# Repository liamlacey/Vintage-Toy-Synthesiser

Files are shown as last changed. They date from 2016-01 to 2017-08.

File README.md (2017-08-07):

# Vintage Toy Synthesiser #

Vintage Toy Synthesiser was the winning project of the [Element14 Music Tech Design Challenge](https://www.element14.com/community/community/design-challenges/musictech) where I converted a wooden vintage toy piano into a standalone digital synthesiser. See the [project blog](https://www.element14.com/community/community/design-challenges/musictech/blog/tags#/?tags=project_vintage) to see the full development process of the project. 

alt vintage-toy-synthesiser

## Project Proposal ##

The original project proposal specification was as follows:
+ Develop a digital synthesis engine that can generate and modify synthesised sounds
+ Modify the existing key mechanism so that it can trigger sounds and control velocity modulation on the synthesis engine
+ Add a set of potentiometers, switches and other controls to the existing piano enclosure for controlling the synthesis engine
+ Add an audio output for connecting the instrument to external speakers and recording equipment
+ Add MIDI I/O so that the instrument can be integrated into existing music production systems
+ Keep the existing aesthetic character of the vintage toy piano

For more info see the full [project proposal](https://www.element14.com/community/community/design-challenges/musictech/blog/2015/12/20/my-music-tech-design-challenge-project-proposal--vintage-toy-synthesiser).

## Hardware/Software Architecture ##

The synthesiser uses a couple of different hardware software platforms:
+ The brain and sound engine of the synthesiser are seperate Linux applications running on a [BeagleBone Black](https://beagleboard.org/black) board, which communicate via software sockets. The brain application is developed in C, and the sound engine application is developed in C++ using the [Maximilian](https://github.com/micknoise/Maximilian) Audio DSP library and [RtAudio](https://www.music.mcgill.ca/~gary/rtaudio/). See the [BeagleBone Black directory](https://github.com/liamlacey/Vintage-Toy-Synthesiser/tree/master/Code/BBB/) for the code for these applications.
+ The keyboard and panel use [Arduino Pro Mini](https://www.arduino.cc/en/Main/ArduinoBoardProMini) boards for sensor/control scanning. The Arduinos communicate with the BeagleBone Black via serial. See the [Arduino directory](https://github.com/liamlacey/Vintage-Toy-Synthesiser/tree/master/Code/Arduino) for the keyboard and panel code.
+ There is a Mac OS X editor application for saving and loading patches on the synth, written in C++ using the [JUCE](https://www.juce.com) framework. See the [VtsEditor directory](https://github.com/liamlacey/Vintage-Toy-Synthesiser/tree/master/Code/VtsEditor) for the code.

For more info on the software architecture see [here](https://www.element14.com/community/community/design-challenges/musictech/blog/2016/02/12/vintage-toy-synthesiser-software-architecture).

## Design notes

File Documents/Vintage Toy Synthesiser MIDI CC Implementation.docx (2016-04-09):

Vintage Toy Synthesiser MIDI CC Implementation

All the parameters of the Vintage Toy Synthesiser can be controlled externally via MIDI CC messages. Also the dials and switches of the front panel can transmit MIDI CCs. Below is a list of all the CCs that are used.

Parameter Category | Parameter | CC Number | CC Range/Values | Notes
Filter | Cutoff | 74 | 0 – 127
| Resonance | 19 | 0 – 127
| LP Mix | 26 | 0 – 127
| HP Mix | 28 | 0 – 127
| BP Mix | 27 | 0 – 127
| Notch Mix | 29 | 0 – 127
Oscillators | Sine Mix | 14 | 0 – 127
| Triangle Mix | 15 | 0 – 127
| Sawtooth Mix | 16 | 0 – 127
| Square Mix | 18 | 0 – 127
| Pulse Mix | 17 | 0 – 127
| Pulse Amount | 3 | 0 – 127
| Sine Note | 33 | 40 – 88 | Bipolar, 64 is midpoint
| Triangle Note | 34 | 40 – 88 | Bipolar, 64 is midpoint
| Sawtooth Note | 35 | 40 – 88 | Bipolar, 64 is midpoint
| Square Note | 37 | 40 – 88 | Bipolar, 64 is midpoint
| Pulse Note | 36 | 40 – 88 | Bipolar, 64 is midpoint
| Phase Spread | 20 | 0 – 127
Amplitude Envelope | Amount | 7 | 0 – 127
| Attack | 73 | 0 – 127
| Decay | 75 | 0 – 127
| Sustain | 79 | 0 – 127
| Release | 72 | 0 – 127
Filter Envelope | Attack | 22 | 0 – 127
| Decay | 23 | 0 – 127
| Sustain | 24 | 0 – 127
| Release | 25 | 0 – 127
LFO | Shape | 50 | 0 – 3 | 0 = sine, 1 = tri, 2 = saw, 3 = square
| Rate | 47 | 0 – 127
| Depth | 48 | 1 – 127 | Bipolar, 64 is midpoint
Modulation Depths | LFO to Amplitude | 58 | 1 – 127 | Bipolar, 64 is midpoint
| LFO to Cutoff | 112 | 1 – 127 | Bipolar, 64 is midpoint
| LFO to Resonance | 56 | 1 – 127 | Bipolar, 64 is midpoint
| Velocity to Amplitude | 63 | 1 – 127 | Bipolar, 64 is midpoint
| Velocity to Cutoff | 109 | 1 – 127 | Bipolar, 64 is midpoint
| Velocity to Resonance | 110 | 1 – 127 | Bipolar, 64 is midpoint
Keyboard/ Voices | Scale | 102 | 0 – 7 | 0 = chromatic, 1 = major, 2 = major pentatonic, 3 = minor, 4 = minor pentatonic, 5 = melodic minor, 6 = harmonic minor, 7 = blues
| Octave | 114 | 61 - 67 | Bipolar, 64 is midpoint
| Transpose | 106 | 58 - 70 | Bipolar, 64 is midpoint
| Voice Mode | 103 | 0 or 127 | 0 = mono, 127 = poly
Global | Distortion Amount | 13 | 0 – 127
| Vintage Amount | 107 | 0 – 127

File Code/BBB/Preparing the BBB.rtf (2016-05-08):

Preparing a BeagleBone Black for the Vintage Toy Synthesiser Project

Note that for steps 1 and 2 I have included a replacement file that can be used instead of doing these steps, however I’m not 100% certain if this file will work on all BBBs which may have slightly different OS’s on them.

1. Enable all UART ports by adding the following line to /boot/uboot/uEnv.txt or /boot/uEnv.txt: optargs=capemgr.enable_partno=BB-UART1,BB-UART2,BB-UART4,BB-UART5. This info was from the following guide - http://tinkernow.com/2015/01/beaglebone-black-rs232-uart-setup/. A reboot is needed for this change to take effect.
2. Set USB audio to be the default audio device:
⁃ Disable HDMI audio by adding or uncommenting the following line from /boot/uboot/uEnv.txt or /boot/uEnv.txt: optargs=capemgr.disable_partno=BB-BONELT-HDMI,BB-BONELT-HDMIN
⁃ Edit the following line of /etc/modprobe.d/alsa-base.conf: options snd-usb-audio index=-2, changing it to: options snd-usb-audio index=0.
⁃ This info was from the following guide - http://andicelabs.com/2014/03/usb-audio-beaglebone/. A reboot is needed for this to take effect.
3. Create the following directories:
⁃ /usr/VintageToySynthProject/
⁃ /usr/VintageToySynthProject/VintageBrain/
⁃ /usr/VintageToySynthProject/VintageSoundEngine/
⁃ /var/vintageToySynthProject/
4. Create a systemd service so that the startup script can be run on boot. See the VintageToySynthProject/vintageToySynthStartup.sh file for more info.

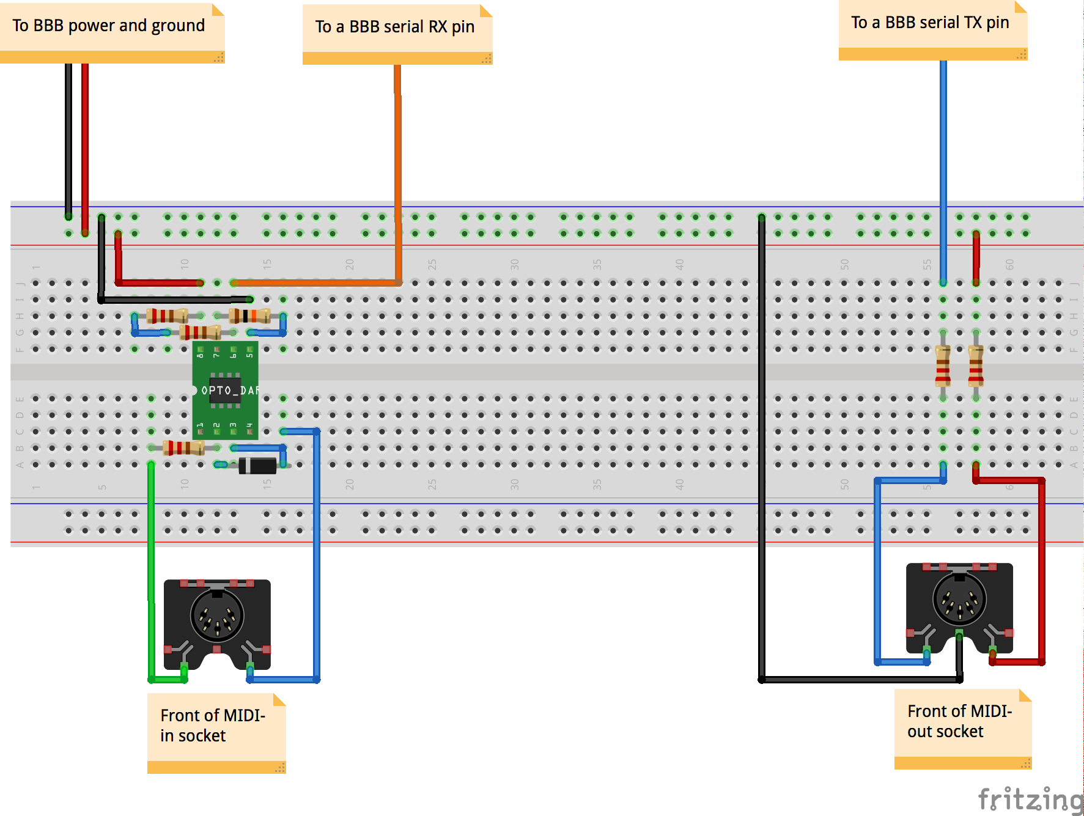
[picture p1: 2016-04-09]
Schematics and Design Files/MIDI/MIDI IO circuit.png

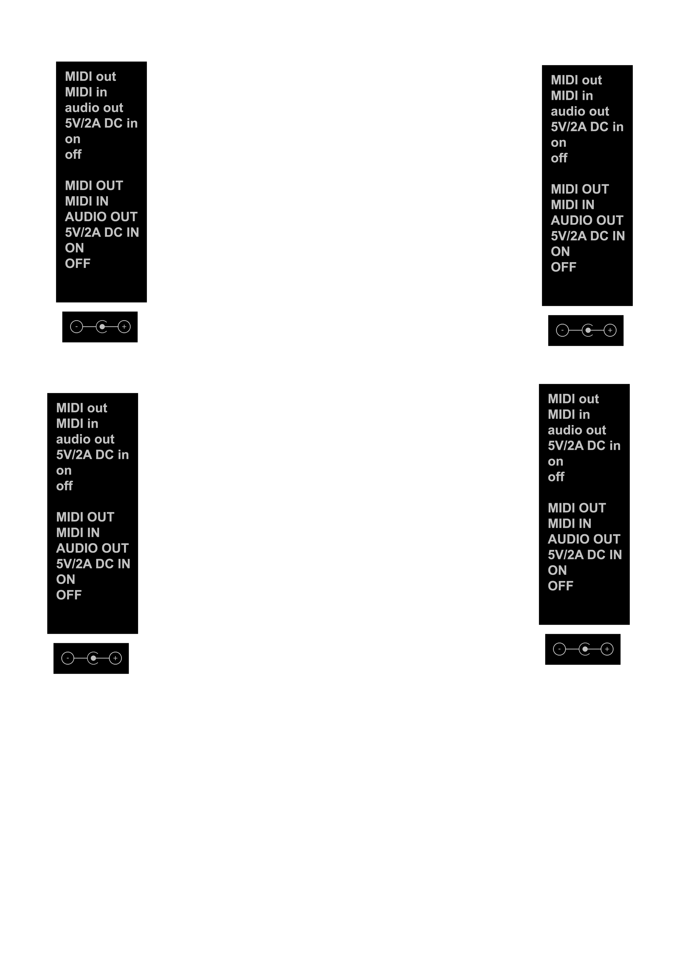
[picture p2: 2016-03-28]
Schematics and Design Files/Panel/Back panel labels.png

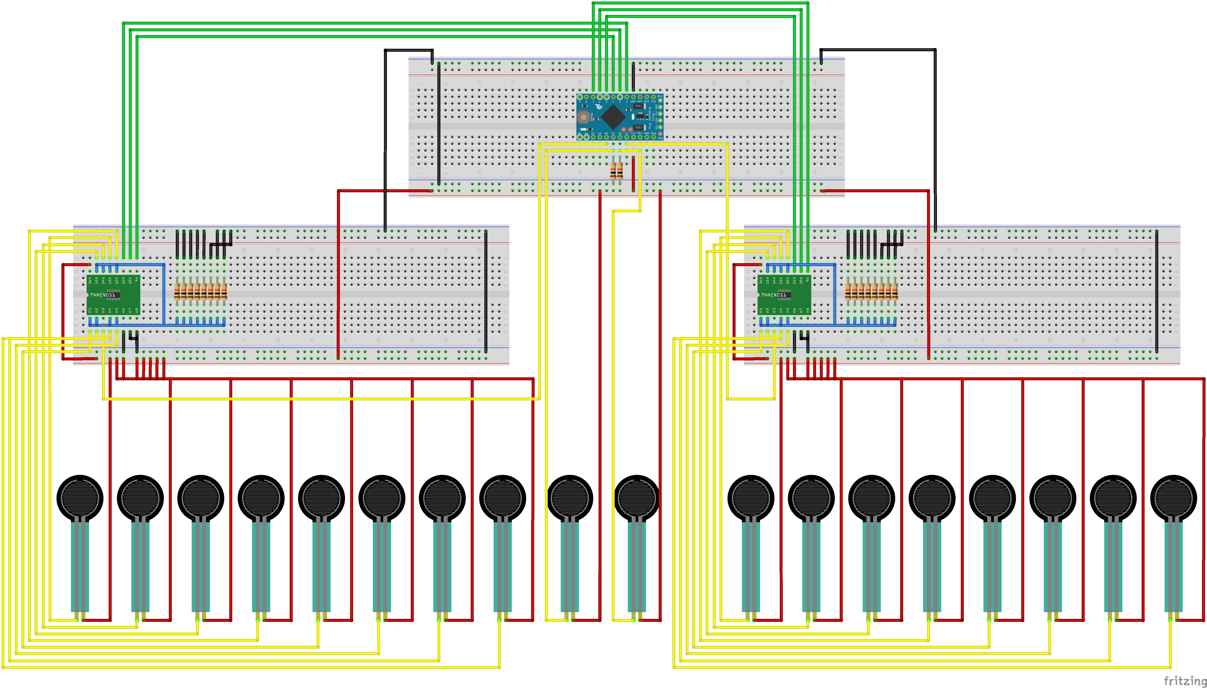
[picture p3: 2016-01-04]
Schematics and Design Files/Keyboard/key mech circuit v2_bb.png

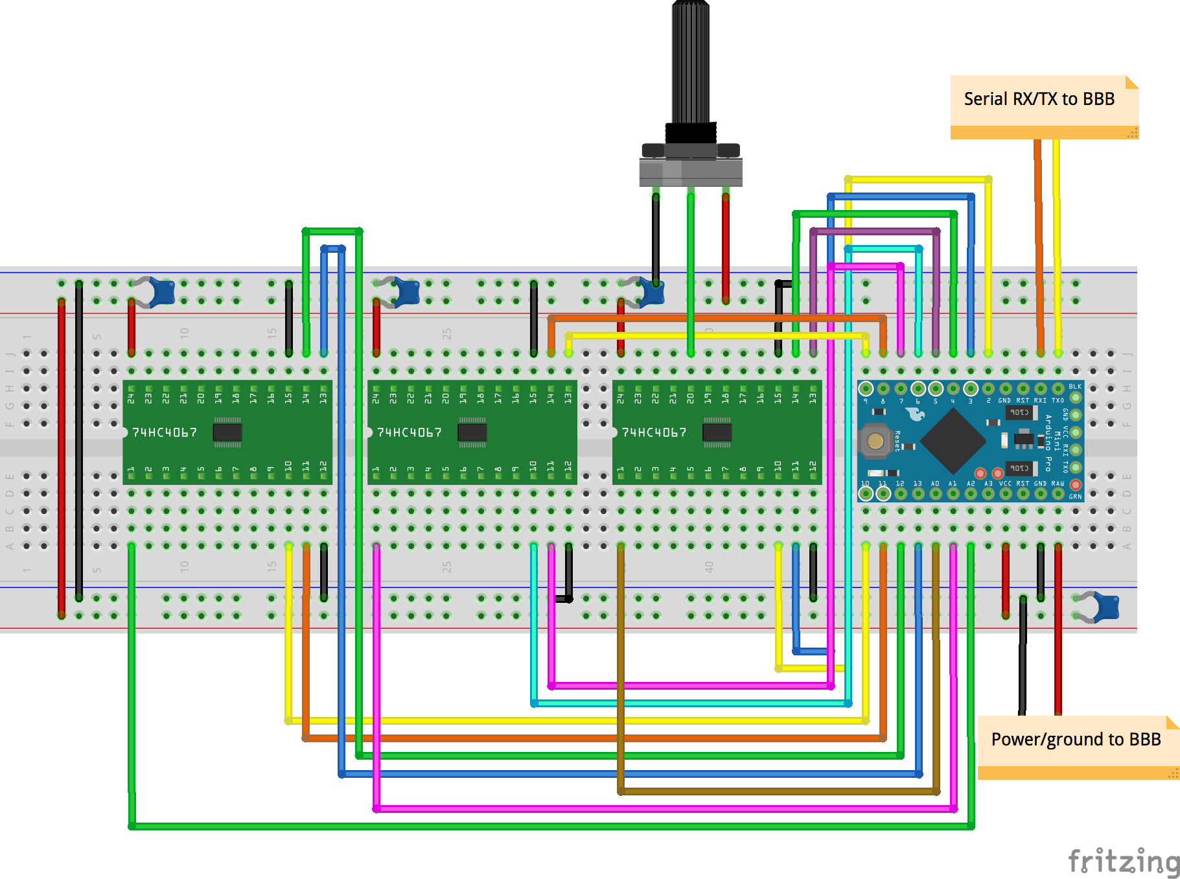
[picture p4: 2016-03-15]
Schematics and Design Files/Panel/panel circuit_bb.png

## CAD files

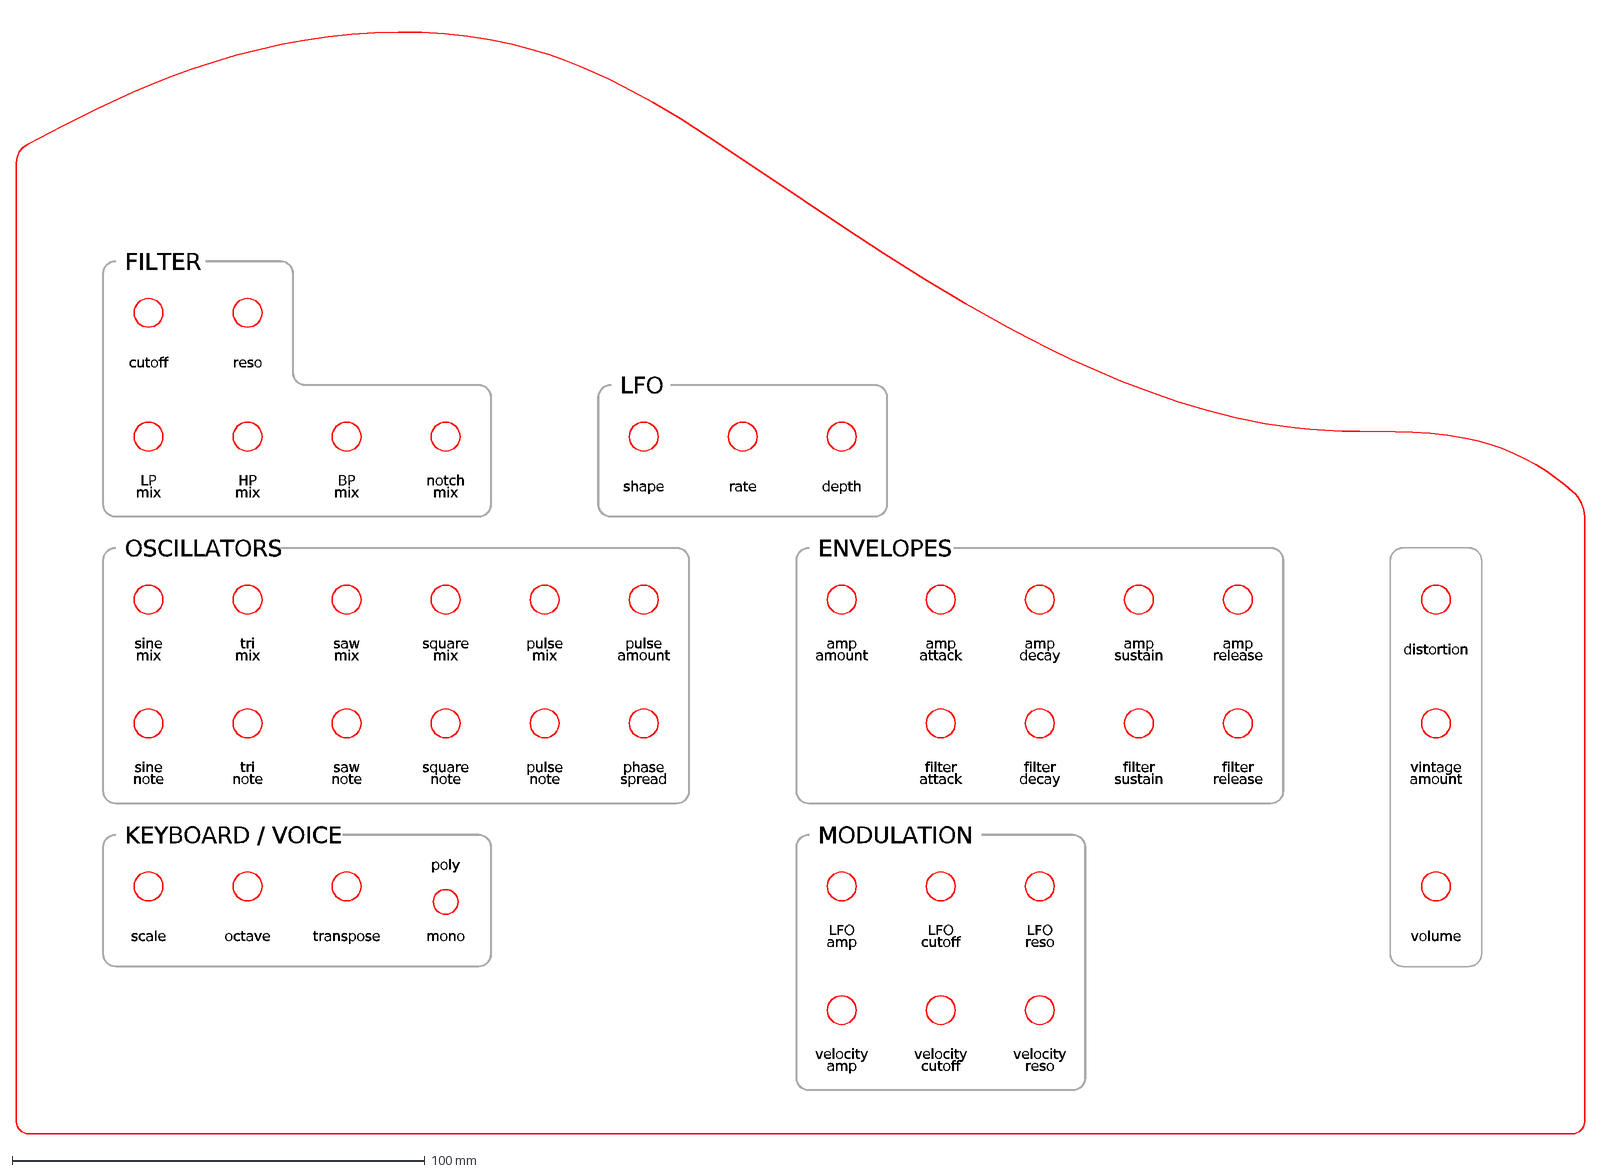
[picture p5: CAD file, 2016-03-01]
Schematics and Design Files/Panel/Synth_Panel_v2_3mm_Acrylic.dxf
cutoff
reso
transpose
scale
octave
mono
pulse amount
phase spread
pulse note
pulse mix
square mix
saw mix
tri mix
sine mix
sine note
tri note
saw note
square note
LP mix
HP mix
BP mix
notch mix
shape
rate
depth
LFO amp
LFO reso
velocity amp
velocity cutoff
velocity reso
distortion
vintage amount
volume
LFO cutoff
poly
FILTER
LFO
OSCILLATORS
amp amount
amp attack
amp decay
amp sustain
amp release
filter attack
filter decay
filter sustain
filter release
ENVELOPES
KEYBOARD / VOICE
MODULATION

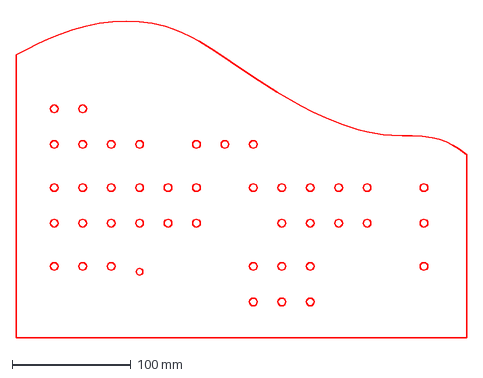
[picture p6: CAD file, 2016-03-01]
Schematics and Design Files/Panel/Synth_Panel_v1_3mm_plywood.dxf
380.0 x 270.9 mm

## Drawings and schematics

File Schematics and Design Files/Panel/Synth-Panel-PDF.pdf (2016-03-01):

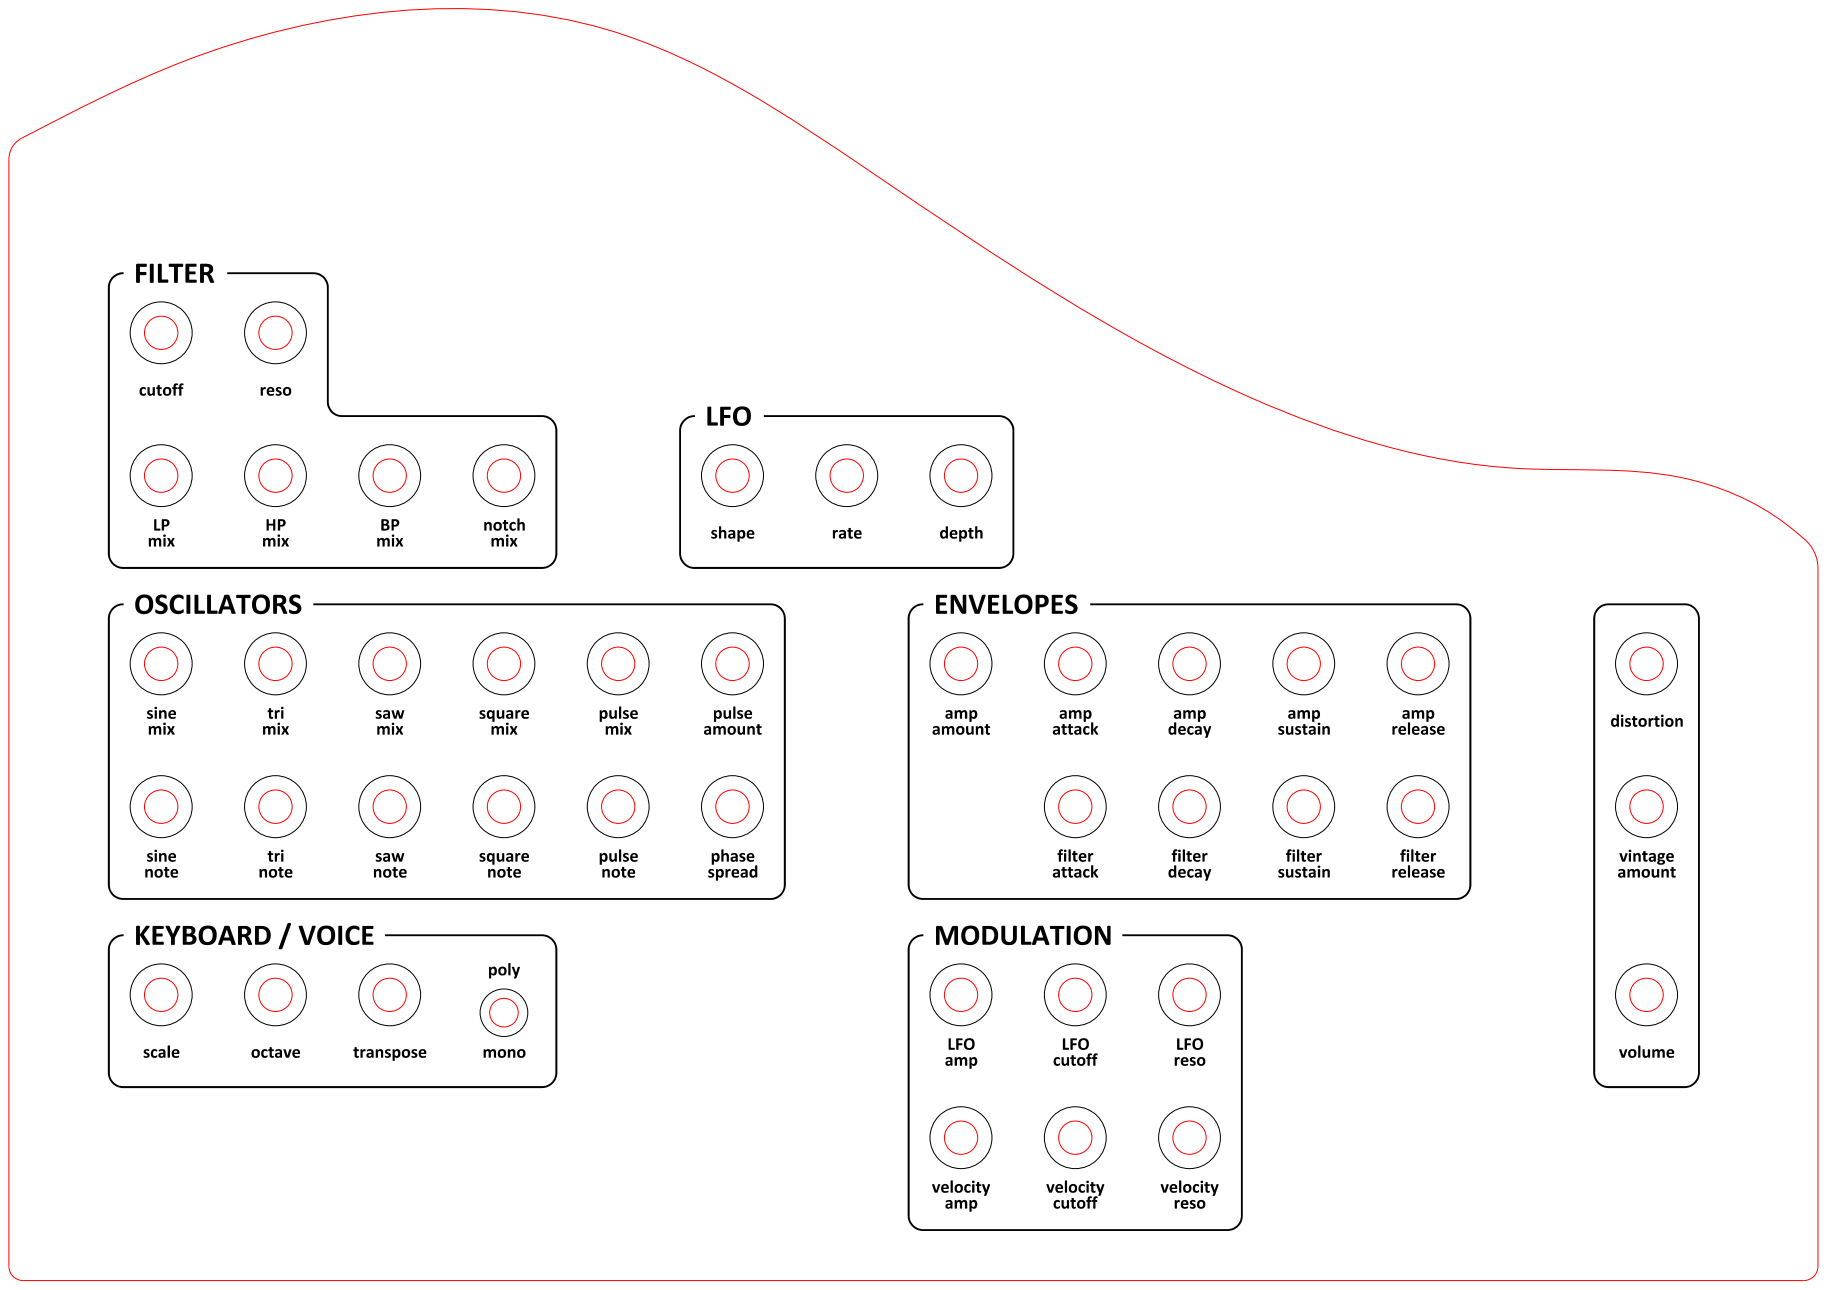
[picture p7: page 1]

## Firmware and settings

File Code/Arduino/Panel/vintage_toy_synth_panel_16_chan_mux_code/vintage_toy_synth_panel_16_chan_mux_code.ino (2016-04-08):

/*
   Vintage Toy Synthesiser Project - panel code.

   This the code for the Arduino Pro Mini attached to the piano's panel.
   This particular code is for using up to 4 16-channel multiplexers.

   All pins are used for the following:
   2 - 5: Mux1 select output pins
   6 - 9: Mux2 select output pins
   10 - 13: Mux3 select output pins
   A4 - A7 (as digital outputs): Mux4 select output pins
   A0: Mux1 input pin
   A1: Mux2 input pin
   A3: Mux3 input pin
   A4: Mux4 input pin

   Note that Mux4 may not be connected, but this code allows for it to be
   used. Mux4 mist be connected if NUM_OF_CONTROLS is greater than 16 * 3.

   //REMEMBER THAT ANY SERIAL DEBUGGING HERE MAY SCREW UP THE SERIAL COMMS TO THE BBB!
*/

//==========================================

//set to 1 when we want to debug to serial monitor rather than send data to the BBB
const byte DEBUG_MODE = 0;

//The number of pots/switches attached
const byte NUM_OF_CONTROLS = 43;

//for dev
const byte FIRST_CONTROL = 0;
const byte LAST_CONTROL = 42;

//The previous anologue value received from each control
int prevAnalogueValue[NUM_OF_CONTROLS] = {0};
//The previous param/MIDI value sent by each control
byte prevParamValue[NUM_OF_CONTROLS] = {0};

//MIDI channel we want to use
const byte midiChan = 0;

const byte VAL_CHANGE_OFFSET = 8;

//==========================================
//param data for each control

struct ControlParamData
{
  const byte cc_num;
  const byte cc_min_val;
  const byte cc_max_val;
  const bool is_depth_param;
};

ControlParamData controlParamData[NUM_OF_CONTROLS] =
{
  {.cc_num = 74, .cc_min_val = 0, .cc_max_val = 127, false}, //0 - PARAM_FILTER_CUTOFF
  {.cc_num = 19, .cc_min_val = 0, .cc_max_val = 127, false}, //1 - PARAM_FILTER_RESO
  {.cc_num = 26, .cc_min_val = 0, .cc_max_val = 127, false}, //2 - PARAM_FILTER_LP_MIX
  {.cc_num = 28, .cc_min_val = 0, .cc_max_val = 127, false}, //3 - PARAM_FILTER_HP_MIX
  {.cc_num = 27, .cc_min_val = 0, .cc_max_val = 127, false}, //4 - PARAM_FILTER_BP_MIX
  {.cc_num = 29, .cc_min_val = 0, .cc_max_val = 127, false}, //5 - PARAM_FILTER_NOTCH_MIX
  {.cc_num = 50, .cc_min_val = 0, .cc_max_val = 3, false}, //6 - PARAM_LFO_SHAPE
  {.cc_num = 47, .cc_min_val = 0, .cc_max_val = 127, false}, //7 - PARAM_LFO_RATE
  {.cc_num = 48, .cc_min_val = 1, .cc_max_val = 127, true}, //8 - PARAM_LFO_DEPTH
  {.cc_num = 14, .cc_min_val = 0, .cc_max_val = 127, false}, //9 - PARAM_OSC_SINE_LEVEL
  {.cc_num = 15, .cc_min_val = 0, .cc_max_val = 127, false}, //10 - PARAM_OSC_TRI_LEVEL
  {.cc_num = 16, .cc_min_val = 0, .cc_max_val = 127, false}, //11 - PARAM_OSC_SAW_LEVEL
  {.cc_num = 18, .cc_min_val = 0, .cc_max_val = 127, false}, //12 - PARAM_OSC_SQUARE_LEVEL
  {.cc_num = 17, .cc_min_val = 0, .cc_max_val = 127, false}, //13 - PARAM_OSC_PULSE_LEVEL
  {.cc_num = 3, .cc_min_val = 0, .cc_max_val = 127, false}, //14 - PARAM_OSC_PULSE_AMOUNT
  {.cc_num = 7, .cc_min_val = 0, .cc_max_val = 127, false}, //15 - PARAM_AEG_AMOUNT
  {.cc_num = 73, .cc_min_val = 0, .cc_max_val = 127, false}, //16 - PARAM_AEG_ATTACK
  {.cc_num = 75, .cc_min_val = 0, .cc_max_val = 127, false}, //17 - PARAM_AEG_DECAY
  {.cc_num = 79, .cc_min_val = 0, .cc_max_val = 127, false}, //18 - PARAM_AEG_SUSTAIN
  {.cc_num = 72, .cc_min_val = 0, .cc_max_val = 127, false}, //19 - PARAM_AEG_RELEASE
  {.cc_num = 13, .cc_min_val = 0, .cc_max_val = 127, false}, //20 - PARAM_FX_DISTORTION_AMOUNT
  {.cc_num = 33, .cc_min_val = 40, .cc_max_val = 88, false}, //21 - PARAM_OSC_SINE_NOTE
  {.cc_num = 34, .cc_min_val = 40, .cc_max_val = 88, false}, //22 - PARAM_OSC_TRI_NOTE
  {.cc_num = 35, .cc_min_val = 40, .cc_max_val = 88, false}, //23 - PARAM_OSC_SAW_NOTE
  {.cc_num = 37, .cc_min_val = 40, .cc_max_val = 88, false}, //24 - PARAM_OSC_SQUARE_NOTE
  {.cc_num = 36, .cc_min_val = 40, .cc_max_val = 88, false}, //25 - PARAM_OSC_PULSE_NOTE
  {.cc_num = 20, .cc_min_val = 0, .cc_max_val = 127, false}, //26 - PARAM_OSC_PHASE_SPREAD
  {.cc_num = 22, .cc_min_val = 0, .cc_max_val = 127, false}, //27 - PARAM_FEG_ATTACK
  {.cc_num = 23, .cc_min_val = 0, .cc_max_val = 127, false}, //28 - PARAM_FEG_DECAY
  {.cc_num = 24, .cc_min_val = 0, .cc_max_val = 127, false}, //29 - PARAM_FEG_SUSTAIN
  {.cc_num = 25, .cc_min_val = 0, .cc_max_val = 127, false}, //30 - PARAM_FEG_RELEASE
  {.cc_num = 107, .cc_min_val = 0, .cc_max_val = 127, false}, //31 - PARAM_GLOBAL_VINTAGE_AMOUNT
  {.cc_num = 102, .cc_min_val = 0, .cc_max_val = 7, false}, //32 - PARAM_KEYS_SCALE
  {.cc_num = 114, .cc_min_val = 61, .cc_max_val = 67, false}, //33 - PARAM_KEYS_OCTAVE
  {.cc_num = 106, .cc_min_val = 58, .cc_max_val = 70, false}, //34 - PARAM_KEYS_TRANSPOSE
  {.cc_num = 103, .cc_min_val = 127, .cc_max_val = 0, false}, //35 - PARAM_VOICE_MODE
  {.cc_num = 58, .cc_min_val = 1, .cc_max_val = 127, true}, //36 - PARAM_MOD_LFO_AMP
  {.cc_num = 112, .cc_min_val = 1, .cc_max_val = 127, true}, //37 - PARAM_MOD_LFO_CUTOFF
  {.cc_num = 56, .cc_min_val = 1, .cc_max_val = 127, true}, //38 - PARAM_MOD_LFO_RESO
  {.cc_num = 9, .cc_min_val = 0, .cc_max_val = 100, false}, //39 - PARAM_GLOBAL_VOLUME
  {.cc_num = 63, .cc_min_val = 1, .cc_max_val = 127, true}, //40 - PARAM_MOD_VEL_AMP
  {.cc_num = 109, .cc_min_val = 1, .cc_max_val = 127, true}, //41 - PARAM_MOD_VEL_CUTOFF
  {.cc_num = 110, .cc_min_val = 1, .cc_max_val = 127, true}, //42 - PARAM_MOD_VEL_RESO
};

//FOR DEVELOPMENT
//ControlParamData controlParamData[NUM_OF_CONTROLS] =
//{
//
//   {.cc_num = 0, .cc_min_val = 0, .cc_max_val = 127},
//   {.cc_num = 1, .cc_min_val = 0, .cc_max_val = 127},
//   {.cc_num = 2, .cc_min_val = 0, .cc_max_val = 127},
//   {.cc_num = 3, .cc_min_val = 0, .cc_max_val = 127},
//   {.cc_num = 4, .cc_min_val = 0, .cc_max_val = 127},
//   {.cc_num = 5, .cc_min_val = 0, .cc_max_val = 127},
//   {.cc_num = 6, .cc_min_val = 0, .cc_max_val = 127},
//   {.cc_num = 7, .cc_min_val = 0, .cc_max_val = 127},
//   {.cc_num = 8, .cc_min_val = 0, .cc_max_val = 127},
//   {.cc_num = 9, .cc_min_val = 0, .cc_max_val = 127},
//   {.cc_num = 10, .cc_min_val = 0, .cc_max_val = 127},
//   {.cc_num = 11, .cc_min_val = 0, .cc_max_val = 127},
//   {.cc_num = 12, .cc_min_val = 0, .cc_max_val = 127},
//   {.cc_num = 13, .cc_min_val = 0, .cc_max_val = 127},
//   {.cc_num = 14, .cc_min_val = 0, .cc_max_val = 127},
//   {.cc_num = 15, .cc_min_val = 0, .cc_max_val = 127},
//   {.cc_num = 16, .cc_min_val = 0, .cc_max_val = 127},
//   {.cc_num = 17, .cc_min_val = 0, .cc_max_val = 127},
//   {.cc_num = 18, .cc_min_val = 0, .cc_max_val = 127},
//   {.cc_num = 19, .cc_min_val = 0, .cc_max_val = 127},
//   {.cc_num = 20, .cc_min_val = 0, .cc_max_val = 127},
//   {.cc_num = 21, .cc_min_val = 0, .cc_max_val = 127},
//   {.cc_num = 22, .cc_min_val = 0, .cc_max_val = 127},
//   {.cc_num = 23, .cc_min_val = 0, .cc_max_val = 127},
//   {.cc_num = 24, .cc_min_val = 0, .cc_max_val = 127},
//   {.cc_num = 25, .cc_min_val = 0, .cc_max_val = 127},
//   {.cc_num = 26, .cc_min_val = 0, .cc_max_val = 127},
//   {.cc_num = 27, .cc_min_val = 0, .cc_max_val = 127},
//   {.cc_num = 28, .cc_min_val = 0, .cc_max_val = 127},
//   {.cc_num = 29, .cc_min_val = 0, .cc_max_val = 127},
//   {.cc_num = 30, .cc_min_val = 0, .cc_max_val = 127},
//   {.cc_num = 31, .cc_min_val = 0, .cc_max_val = 127},
//   {.cc_num = 32, .cc_min_val = 0, .cc_max_val = 127},
//   {.cc_num = 33, .cc_min_val = 0, .cc_max_val = 127},
//   {.cc_num = 34, .cc_min_val = 0, .cc_max_val = 127},
//   {.cc_num = 35, .cc_min_val = 0, .cc_max_val = 127},
//   {.cc_num = 36, .cc_min_val = 0, .cc_max_val = 127},
//   {.cc_num = 37, .cc_min_val = 0, .cc_max_val = 127},
//   {.cc_num = 38, .cc_min_val = 0, .cc_max_val = 127},
//   {.cc_num = 39, .cc_min_val = 0, .cc_max_val = 127},
//   {.cc_num = 40, .cc_min_val = 0, .cc_max_val = 127},
//   {.cc_num = 41, .cc_min_val = 0, .cc_max_val = 127},
//   {.cc_num = 42, .cc_min_val = 0, .cc_max_val = 127},
//};

void setup()
{
  //Setup serial comms for sending MIDI messages to BBB.
  //We don't need to use the MIDI baud rate (31250) here, as we're sending the messages to a general
  //serial output rather than a MIDI-specific output.
  Serial.begin(38400);

  //set all needed digital output pins
  for (byte i = 2; i <= 13; i++)
  {
    pinMode (i, OUTPUT);
  }

  pinMode (A4, OUTPUT);
  pinMode (A5, OUTPUT);
  pinMode (A6, OUTPUT);
  pinMode (A7, OUTPUT);

}

void loop()
{
  byte input_to_read;
  byte mux_input_pin;
  byte first_select_pin;

  //for each control
  for (byte control_num = FIRST_CONTROL; control_num <= LAST_CONTROL; control_num++)
  {
    //==========================================
    //==========================================
    //==========================================
    //Read analogue control input...

    //Select the mux/analogue pin we want to read from based on the control number
    //FIXME: there are probably equations I can use here instead.
    if (control_num < 16)
    {
      input_to_read = A0;
      mux_input_pin = control_num;
      first_select_pin = 2;
    }
    else if (control_num < 32)
    {
      input_to_read = A1;
      mux_input_pin = control_num - 16;
      first_select_pin = 6;
    }
    else if (control_num < 48)
    {
      input_to_read = A2;
      mux_input_pin = control_num - 32;
      first_select_pin = 10;
    }
    else
    {
      input_to_read = A3;
      mux_input_pin = control_num - 48;
      first_select_pin = A4;
    }

    //select the input pin on the mux we want to read from, by splitting
    //the mux input pin into bits and sending the bit values to mux select pins.
    int b0 = bitRead (mux_input_pin, 0);
    int b1 = bitRead (mux_input_pin, 1);
    int b2 = bitRead (mux_input_pin, 2);
    int b3 = bitRead (mux_input_pin, 3);
    digitalWrite (first_select_pin, b0);
    digitalWrite (first_select_pin + 1, b1);
    digitalWrite (first_select_pin + 2, b2);
    digitalWrite (first_select_pin + 3, b3);

    //read the input value
    int read_val = analogRead (input_to_read);

    //==========================================
    //==========================================
    //==========================================
    //Process analogue control input...

    //if the read control value is greater that +/-VAL_CHANGE_OFFSET from the last value
    //this is a quick dirty hack to prevent jitter
    if ((read_val > prevAnalogueValue[control_num] + VAL_CHANGE_OFFSET) ||
        (read_val < prevAnalogueValue[control_num] - VAL_CHANGE_OFFSET) ||
        (read_val == 0 && prevAnalogueValue[control_num] != 0) ||
        (read_val == 1023 && prevAnalogueValue[control_num] != 1023))
    {

      // Serial.print(control_num);
      // Serial.print(" ");
      // Serial.println(read_val);

      //store the value
      prevAnalogueValue[control_num] = read_val;

      //convert the control value into a param/MIDI CC value
      byte param_val = ConvertControlValToParamVal (control_num);

      //if this control is for a bipolar depth parameter
      if (controlParamData[control_num].is_depth_param == true)
      {
        //make sure the control definietly centres on the centre value of the parameter
        //by setting a certain window around the centre value to be set to the centre value

        if (param_val >= 63 && param_val <= 65)
        {
          param_val = 64;

        } //if (param_val >= 63 && param_val <= 65)

      } //if (controlParamData[control_num].is_bipolar_control == true)

      //if the param val is different from the last param val
      if (prevParamValue[control_num] != param_val)
      {
        //store the value
        prevParamValue[control_num] = param_val;

        //Send the param value as a MIDI CC message
        SendMidiMessage (0xB0 + midiChan, controlParamData[control_num].cc_num, prevParamValue[control_num]);

      } //if (prevParamValue[control_num] != param_val)

    } //if (prevAnalogueValue[control_num] != read_val)

    //slow down control reading to help prevent jitter.
    //it also means when pots are turned fast they only send a small number of values
    delay (2);

  } //for (byte control_num; control_num < NUM_OF_CONTROLS; control_num++)

  //==========================================
  //==========================================
  //==========================================
  //Read serial input...

  //if there is something to read on the serial port
  if (Serial.available())
  {
    //Serial.println ("Received messages from serial input");

    byte midi_in_buf[64];

    int num_of_bytes = Serial.readBytes (midi_in_buf, 64);

    //if received a request for all panel control values
    if (num_of_bytes == 3 && midi_in_buf[0] == 0xB0 && midi_in_buf[1] == 127 && midi_in_buf[2] == 1)
    {
      //send back all control values
      for (byte control_num = 0; control_num < NUM_OF_CONTROLS; control_num++)
      {
        SendMidiMessage (0xB0 + midiChan, controlParamData[control_num].cc_num, prevParamValue[control_num]);
      }

    } //if (num_of_bytes == 3 && midi_in_buf[0] == 0xB0 && midi_in_buf[1] = 127 && midi_in_buf[2] == 1)

  } //if (Serial.available())

}

//=====================================================
//=====================================================
//=====================================================
//Converts a control value into a param/MIDI CC value

byte ConvertControlValToParamVal (byte control_num)
{
  byte result;

  result = ((((float)controlParamData[control_num].cc_max_val - (float)controlParamData[control_num].cc_min_val) * (float)prevAnalogueValue[control_num]) / 1023.0) + (float)controlParamData[control_num].cc_min_val;

  return result;
}

//=====================================================
//=====================================================
//=====================================================
//Sends a 3 byte MIDI message to the serial output

void SendMidiMessage (byte cmd_byte, byte data_byte_1, byte data_byte_2)
{
  byte buf[3] = {cmd_byte, data_byte_1, data_byte_2};

  if (!DEBUG_MODE)
  {
    Serial.write (buf, 3);
  }

  else
  {
    Serial.print(buf[0]);
    Serial.print(" ");
    Serial.print(buf[1]);
    Serial.print(" ");
    Serial.println(buf[2]);
  }
}

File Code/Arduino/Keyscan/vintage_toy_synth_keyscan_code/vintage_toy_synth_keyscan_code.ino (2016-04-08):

//Toy Piano Synth Code, for front velostat switches only using multiplexers for the first and last 8 keys, with dedicated inputs for the middle two keys.
//TODO: improve this description
//*/

//TODO: document and DEFINE the inputs and outputs we are using for this code

//FIXME: some keys/sensors don't work as well as others - sensitivity is bad and can't reach high pressure values.
//If I can't fix these in the hardware, add fixes in the software (e.g. have upper limit pressure values for each key).

//REMEMBER THAT ANY SERIAL DEBUGGING HERE MAY SCREW UP THE SERIAL COMMS TO THE BBB!

//========================================================================================

//Number of keys on the piano
const int NUM_OF_KEYS = 18;

//MIDI channel we want to use
const int midiChan = 0;

//=======================================================================================

int INIT_PHASE_TIME = 10;

int PRESSURE_OFFSET = 100;

//Variables for storing certain values
int triggerVal[NUM_OF_KEYS] = {0};
bool noteIsOn[NUM_OF_KEYS] = {false};

unsigned long triggerTime[NUM_OF_KEYS] = {0};
int triggerInitVal[NUM_OF_KEYS] = {0};
bool inInitPhase[NUM_OF_KEYS] = {false};
byte prevPressureVal[NUM_OF_KEYS] = {0};

bool testLedState = false;

//array that holds the max analogue values they each sensor key can reach
const int maxSensorVals[NUM_OF_KEYS] =
{
  530, //0
  630, //1
  570, //2
  670, //3
  680, //4
  560, //5
  629, //6
  650, //7
  640, //8
  630, //9
  580, //10
  630, //11
  570, //12
  610, //13
  580, //14
  270, //15
  650, //16
  590 //17
};

void setup()
{
  //For sending MIDI messages to BBB.
  //We don't need to use the MIDI baud rate (31250) here, as we're sending the messages to a general
  //serial output rather than a MIDI-specific output.
  Serial.begin(38400);

  pinMode(2, OUTPUT);    // mux1 s0
  pinMode(3, OUTPUT);    // mux1 s1
  pinMode(4, OUTPUT);    // mux1 s2

  pinMode(5, OUTPUT);    // mux2 s0
  pinMode(6, OUTPUT);    // mux2 s1
  pinMode(7, OUTPUT);    // mux2 s2

  pinMode(13, OUTPUT);    // LED
}

void loop()
{
  //repeat the below code for each input/key
  for (int count; count < NUM_OF_KEYS; count++)
  {
    triggerVal[count] = 0;

    //==========================================
    //==========================================
    //==========================================
    //Read input
    //FIXME: this code could be tidier

    if (count < 8)
    {
      //select the bit/input
      int r0 = bitRead (count, 0);
      int r1 = bitRead (count, 1);
      int r2 = bitRead (count, 2);
      digitalWrite (2, r0);
      digitalWrite (3, r1);
      digitalWrite (4, r2);

      //read the input value
      triggerVal[count] = analogRead(A0);
    }

    else if (count == 8)
    {
      triggerVal[count] = analogRead(A1);
    }

    else if (count == 9)
    {
      triggerVal[count] = analogRead(A2);
    }

    else if (count > 9)
    {
      //select the bit/input

      int mux_input = count - 10;

      int r0 = bitRead (mux_input, 0);
      int r1 = bitRead (mux_input, 1);
      int r2 = bitRead (mux_input, 2);
      digitalWrite (5, r0);
      digitalWrite (6, r1);
      digitalWrite (7, r2);

      //read the input value
      triggerVal[count] = analogRead(A3);
    }

    //    if (triggerVal[count] > 0)
    //    {
    //      Serial.print(count);
    //      Serial.print(": ");
    //      Serial.println(triggerVal[count]);
    //    }

    //==========================================
    //==========================================
    //==========================================
    //Process input

    //==========================================
    //Initial press stuff (for working out velocity)

    //========================
    //if we've got the initial press of a key
    if (triggerVal[count] > 0 && inInitPhase[count] == false && noteIsOn[count] == false)
    {
      //stored the current time
      triggerTime[count] = millis();

      triggerInitVal[count] = 0;
      inInitPhase[count] = true;
    }

    //========================
    //if we're still holding down a key within the initial phase
    else if (triggerVal[count] > 0 && inInitPhase[count] == true && millis() < (triggerTime[count] + INIT_PHASE_TIME) && noteIsOn[count] == false)
    {
      //if the current val is higher than the current init val
      if (triggerVal[count] > triggerInitVal[count])
      {
        //store the current val
        triggerInitVal[count] = triggerVal[count];
      }
    }

    //========================
    //if a key is released before the initial phase is over
    else if (triggerVal[count] == 0 && inInitPhase[count] == true && noteIsOn[count] == false)
    {
      //reset inInitPhase
      inInitPhase[count] == false;
      triggerInitVal[count] = 0;
    }

    //==========================================
    //Process note-on's and note-off's

    //========================
    //if in the initial phase and current time is +INIT_PHASE_TIME of the initial trigger time
    else if (triggerVal[count] > 0 && inInitPhase[count] == true && millis() >= (triggerTime[count] + INIT_PHASE_TIME) && noteIsOn[count] == false)
    {
      //Work out a velocity value based on the init val...

      //Serial.print("Init val: ");
      //Serial.println(triggerInitVal[count]);

      //use two-thirds of the max sensor value as the top velocity value, as it seems to work well.
      int velocity = (127.0 * (float)triggerInitVal[count]) / (((float)maxSensorVals[count] / 3.0));

      if (velocity > 127)
      {
        velocity = 127;
      }

      inInitPhase[count] = false;

      if (velocity > 0)
      {
        //Send MIDI note-on message
        SendMidiMessage (0x90 + midiChan, count, velocity);

        //flag that the note is on
        noteIsOn[count] = true;

        //test feedback
        digitalWrite (13, HIGH);

      } //if (velocity > 0)

    }

    //========================
    //if the note is currently on and we get a key release
    else if (triggerVal[count] == 0 && noteIsOn[count] == true)
    {
      //Send MIDI note-on message
      SendMidiMessage (0x80 + midiChan, count, 0);

      noteIsOn[count] = false;

      //test feedback
      digitalWrite (13, LOW);
    }

    //Process poly pressure

    //========================
    //If we've got a key/pressure value of above the init input val whilst the note is on
    else if (triggerVal[count] >= (triggerInitVal[count] + PRESSURE_OFFSET) && triggerInitVal[count] != 0 && noteIsOn[count] == true)
    {
      //Work out pressure value based on the difference between the current val and the init val...
      //FIXME: this algorithm only really works for light presses.
      //If a heavy press, we don't want so much offset - implement an equation for this.

      //FIXME: make sure a pressure value of 0 is sent on key release if needed

      int init_pressure = triggerInitVal[count] + PRESSURE_OFFSET;
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

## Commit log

2015-12-31 Added arduino keyscan code
2015-12-31 Removed all debugging, sending MIDI messages over serial, using LED on pin 13 to show key presses.
2016-01-01 Added arduino mega code for converting serial messages from the pro mini to USB MIDI (using HIDuino on the mega)
2016-01-01 Change pins being used (as I seem to have destroyed some of the digital pins when soldering the arduino!)
2016-01-04 Added key mech circuit diagram.
    [key mech circuit v2.fzz]
2016-01-10 Added BBB test code for reading data from the key mech, connected to UART1.
2016-01-18 Removed initialisations from maximilian.h - for some reason the gcc compiler on the BBB didn't like these. Hopefully I haven't broken anything in doing this.
    [maximilian.h]
2016-01-28 Setting up sockets in vintageBrain for talking to the sound engine app
2016-01-28 Got vintageSoundEngine working like the test maxi project was, but with main, setup, and play in the same file, and with a main loop which will be used to listen for messages from the vintageBrain so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
2016-01-28 Added more debugging to vintageAudioEngine. Including files so that I can setup a socket in here.
2016-01-29 Setup sockets within vintageSoundEngine and tested sending data from vintageBrain. All appears to work :).
2016-01-29 Createed a vintageVoice class that will handle all the audio processing for each voice. Currently just got the original maxi test code in there, and just processing one voice.
2016-01-29 Got vintageSoundEngine correctly processing MIDI messages coming from the vintageBrain socket. vintageBrain is currently sending a test stream of note-on messages. haven't tested sending different me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
2016-01-29 Got MIDI note on messages coming from vintageBrain changing the pitch of a simple oscillator.
2016-01-29 Changed a couple of names and data types.
2016-01-30 Created a structure for holding parameter data, as well a const array for storing default values. Created a function for converting param user values to voice values. Got vintageBrain sending differe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
2016-01-30 Implemented all oscillators, filter, and both envelopes, all fully controllable.
2016-01-30 Setup vintageBrain to listen for messages from the MIDI interface on UART2, using a poll system so that it can listen to messages from the keyboard too. vintageBrain now processes MIDI messages corre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
2016-02-07 Now processing two voices (well, the second voice is currently being unused, but it appears to be working).
2016-02-07 Changed the range of a couple of parameters.
2016-02-07 Properly using velocity to modulate AEG amount. Not taking into acount vel->amp mod depth yet though.
2016-02-10 Created most of the Arduino panel code for the 16-chan mux circuit, which scans all controls and sends any changes over serial using MIDI CC messages. Left to do: list all the paramater data for each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
2016-02-12 Created a simple app that just sets up and closes serial comms for all used UARTs using the old serial comms setup code, as I've found after booting the BBB, unless I run this code first, my new seri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
    [initSerialPorts.c]
2016-02-13 Dissabled sending aftertouch - seems like my current synth engine on the BBB can't handle it, even if just sending to MIDI-out. Before doing this I did improve the code a little bit so that it doesn'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
    [vintage_toy_synth_keyscan_code.ino]
2016-02-13 Finished implemting the receiving of aftertouch messages from the keyboard (though aftertouch is currently being disabled on the key mech)
2016-02-16 Corrected the analogue to midi value conversion code in the panel arduino code. Set up for testing one pot.
    [vintage_toy_synth_panel_16_chan_mux_code.ino]
2016-02-20 A couple of comments and makefile changes
2016-02-22 Set it so that the LFO phase is only reset on note on messages when the amp evelope currently 0, allowing it to not always be reset in mono mode.
2016-02-23 Added a define and TODO for implementing a 'sound engine ready and needs current panel settings' message.
2016-02-24 Changed keyscan code for new non-broken Arduino
    [vintage_toy_synth_keyscan_code.ino]
2016-02-24 Simple Arduino test app code that sends a sequence of MIDI messages over serial
2016-03-01 Added design files for panel design
    [Synth_Panel_v1_3mm_plywood.dxf, Synth_Panel_v2_3mm_Acrylic.dxf, key mech circuit v2.fzz]
2016-03-07 Implemented the function of the VTS Editor requesting all current patch data from the synth, and the synth sending it all back. Completely untested.
2016-03-09 Fixed the issue with the keyscan sending ghost notes.
    [vintage_toy_synth_keyscan_code.ino]
2016-03-10 Implemented a list of max sensor values in the keyscan code so that velocity and pressure sensitive are the same for each key. Need to populate the value list with the correct values though.
    [vintage_toy_synth_keyscan_code.ino]
2016-03-11 Reorganised repo
    [Synth_Panel_v1_3mm_plywood.dxf, Synth_Panel_v2_3mm_Acrylic.dxf, key mech circuit v2.fzz]
2016-03-12 Improved velocity sensitivity so that all keys are now similarish.
2016-03-15 Set it so now when changing keyboard scale, octave, or transpose it instantly updates the pitch of any playing note/voices instead of just killing them. This is completely untested and involved quite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
2016-03-15 Added panel circuit diagrams
    [panel circuit.fzz]
2016-03-21 Panel stuff: Increased panel control scanning speed to prevent stepping in param changes. Correct voice mode switch values. Removed debugging that may have been sending invalid messages to the BBB.
    [vintage_toy_synth_panel_16_chan_mux_code.ino]
2016-03-21 Stopped only processing the audio code if envAmpOut is greater than 0, as this was causing weird behaviour with the filter envelope
2016-03-27 Added a button to VTS editor for reseting the synth back to the current panel settings
2016-03-27 Allowed VTS editor to disable/enable the synth panel (to prevent panel jitter from ruining loaded patches)
2016-04-04 Changed the user/control values of the depth controls to be 1-127 instead of 0-127, so that 64 is the actual mid point and converts to a true 0. This fixes the issue where modulation could be heard e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
    [vintage_toy_synth_panel_16_chan_mux_code.ino]
2016-04-08 Halfed the pitch offset that vintage amount applies to make the effect more subtle.
2016-04-08 Using floats instead of ints for the vintage amount oscillator pitch offsets.
2016-04-08 Improved keyboard velocity curve
2016-04-08 Think I've finally settled on using a delay time of 2 when reading panel controls, as this really does improve jitter and cross talk issues. Makes things more steppy, but this is fixable in the voice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
    [vintage_toy_synth_panel_16_chan_mux_code.ino]
2016-04-08 Made the filter cutoff slightly smoother when using the panel control. Any smoother though results in fast turns creating a lag.
2016-04-09 Added MIDI IO curcuit diagram.
    [MIDI IO circuit.fzz]
2017-08-08 Added support for a single USB-MIDI device input within VintageBrain, as a quick way of testing the VTS applications on an RPi without the keyboard, panel, or MIDI interface connected. This involved 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
2017-08-17 Setting the RTAudio object audio device ID to be that of the USB audio device, so that sound is outputted from the USB audio device.
2017-08-17 Fixed an issue where the first connected USB MIDI device wouldn't always be C1 on the system, so now it looks for C0-C16. It still will only connect to one MIDI device at a time though. Haven't teste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
